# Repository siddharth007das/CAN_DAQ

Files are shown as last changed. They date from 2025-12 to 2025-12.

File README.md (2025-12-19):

# CAN-DAQ ESP32 PCB

This is the PCB for the ESP32 that is used in the CAN-DAQ project. Gerber files, BOM, and 3D printing files for the case are all available in the releases section on GitHub.

## Pin-out
Refer to the pin-out for [ESP32-S3 DevKitC 1](https://docs.espressif.com/projects/esp-idf/en/latest/esp32s3/hw-reference/esp32s3/user-guide-devkitc-1.html).

official pin-out

### Pin-out for the microcontroller

| ESP Pin | Function | Connected to |
| --- | --- | --- |
| GPIO6 | CAN Rx | MCP2651FD CAN Rx |
| GPIO7 | CAN Tx | MCP2651FD CAN Tx |
| GPIO4 | CAN Standby | MCP2651FD STBY (10k pull-down) |
| GPIO5 | Status | Status LED |
| GPIO46 | Disable debug log | Pull-up resistor (10k to 5V) |

### Pin-out for the DE9 CAN connector
| DE9 Pin | Function | Connected to |
| --- | --- | --- |
| 2 | CANL | MCP2651FD CANL |
| 7 | CANH | MCP2651FD CANH |
| 3 | CAN GND | GND |
| shield |  | GND |

## USB specification
| Property | Value |
| --- | --- |
| USB standard | USB 2.0 |
| Connector | USB micro-B |
| Maximum speed | 3 Mbit/s |

## Design decisions

### DE9 ground
The CAN ground of the DE9 connector is connected to the main ground of the circuit. In case the differential voltages are not referenced to the same ground, the CAN bus will not work properly otherwise.

Sources:
- https://electronics.stackexchange.com/a/519395/323565
- https://electronics.stackexchange.com/q/476129/323565

### ESP32 log output disable
The ESP32 has a pull-up resistor on GPIO46 to disable the debug log output. We do this to make ensure that our GUI software receives only clean data.

Source: [Section "8.3 ROM Messages Printing Control" of the ESP32-S3 Technical Reference Manual](https://www.espressif.com/sites/default/files/documentation/esp32-s3_technical_reference_manual_en.pdf)

### CAN Transceiver output enable
The MCP2651FD CAN transceiver has a STBY pin that can be used to enable or disable the transceiver. We use GPIO4 to control this pin. The STBY pin is pulled down to ground with a 10k resistor (enabled) by default.

Source: [Section "1.1 Mode Control Block" of the MCP2651FD datasheet](https://ww1.microchip.com/downloads/en/DeviceDoc/20005284A.pdf)

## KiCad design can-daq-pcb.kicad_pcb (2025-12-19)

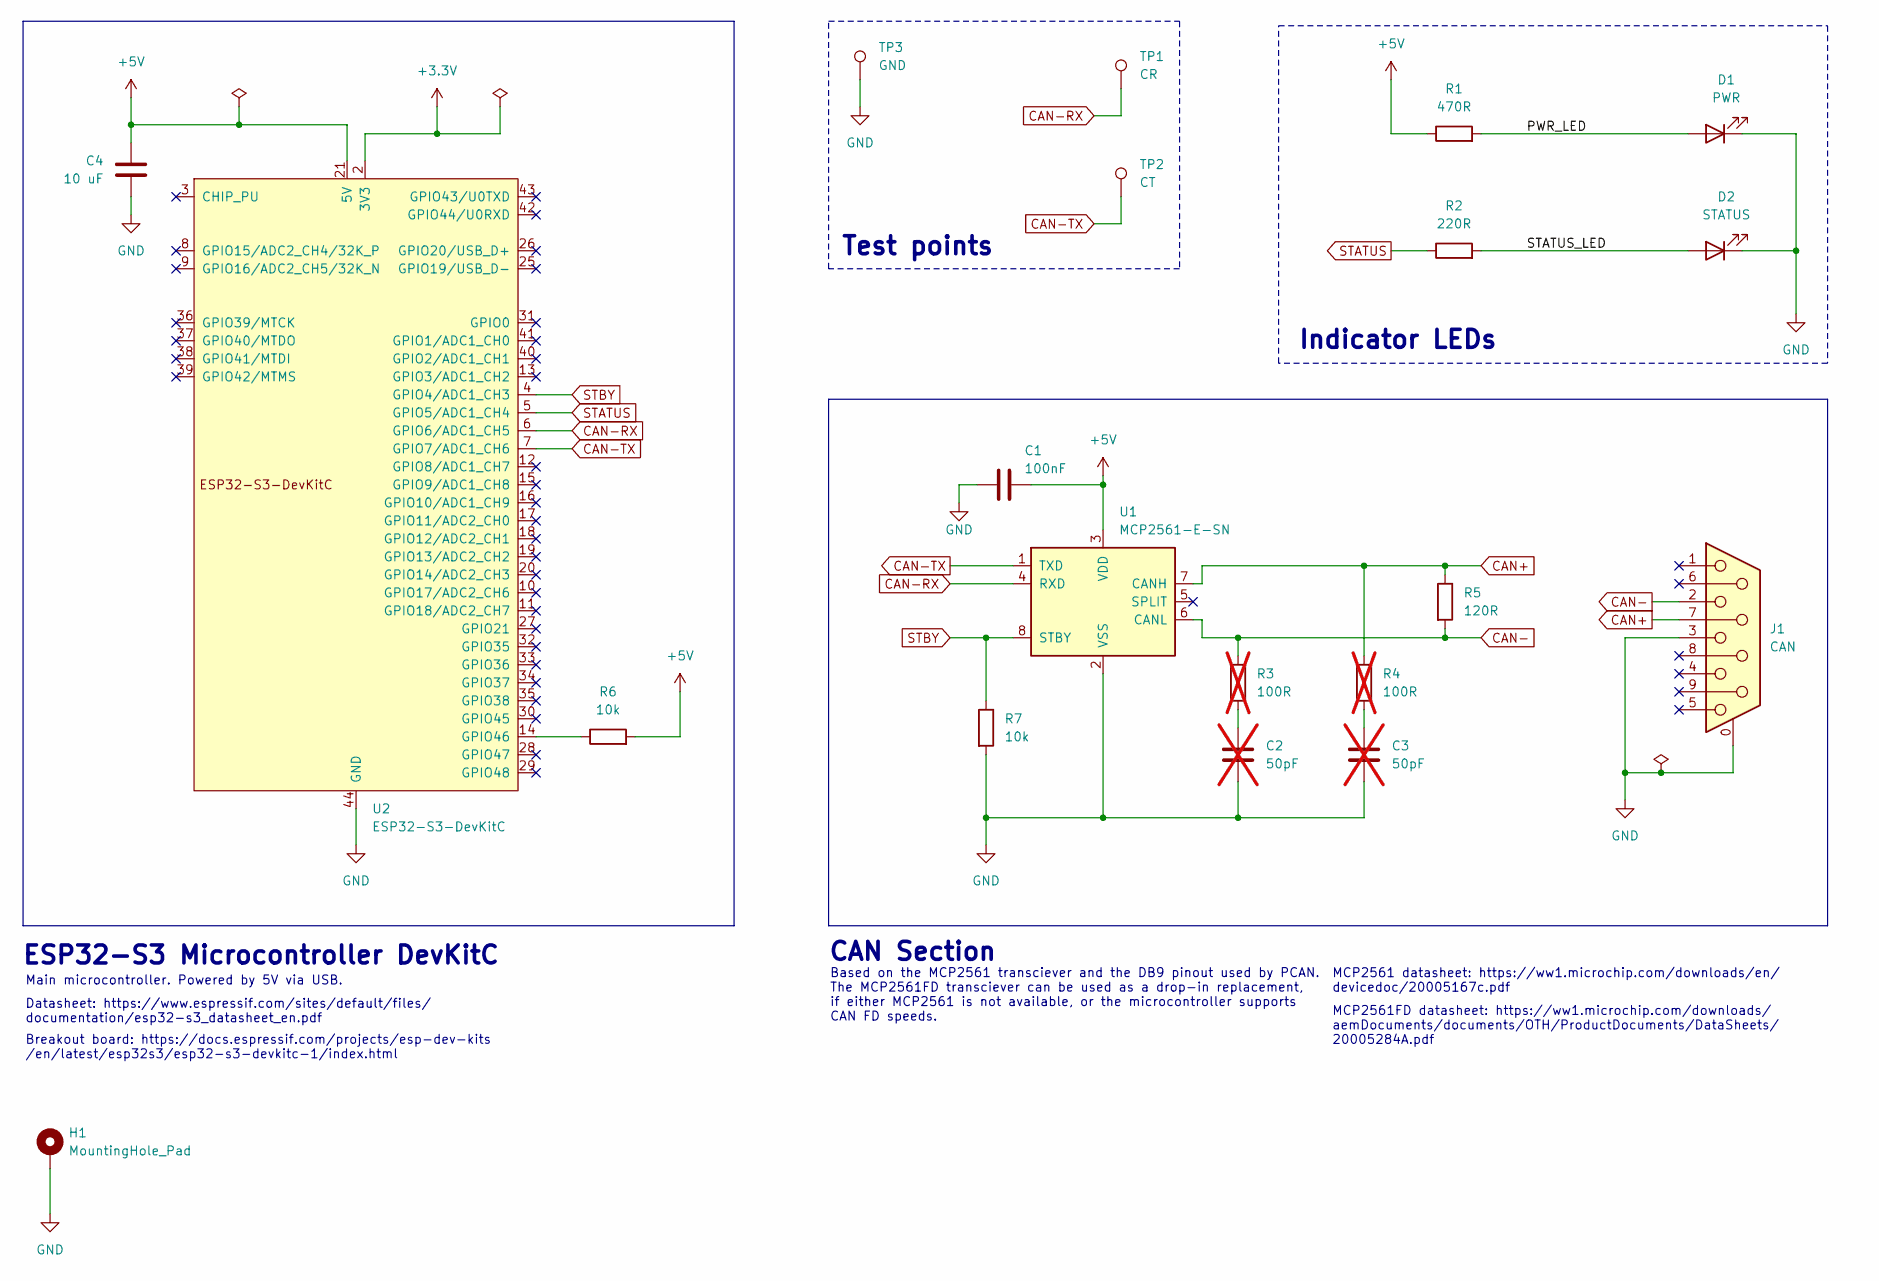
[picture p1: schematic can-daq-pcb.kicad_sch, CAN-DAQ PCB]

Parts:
C1: 100nF; C_0805_2012Metric_Pad1.18x1.45mm_HandSolder; MPN CC0805KRX7R9BB104; JLC C49678
C2, C3: 50pF; C_1206_3216Metric_Pad1.33x1.80mm_HandSolder; MPN FCC1206N470J102DT; JLC C5137553; not fitted
C4: 10 uF; C_1206_3216Metric_Pad1.33x1.80mm_HandSolder; MPN CL31A106KBHNNNE; JLC C13585
D1: PWR; LED_D3.0mm; MPN TZ-L2-03YYBR2RDJ30-003; JLC C779429
D2: STATUS; LED_D3.0mm; MPN TJ-L3FYTGCBMCGSFLC6B-A5; JLC C330760
H1: MountingHole_Pad; MountingHole_3.2mm_M3_Pad_Via
J1: CAN; DSUB-9_Female_Horizontal_P2.77x2.84mm_EdgePinOffset4.94mm_H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; MPN DS1037-09FNAKT74-0CC; JLC C75749
R1: 470R; R_1206_3216Metric_Pad1.30x1.75mm_HandSolder; MPN RC1206FR-07470RL; JLC C114945
R2: 220R; R_1206_3216Metric_Pad1.30x1.75mm_HandSolder; MPN 1206W4J0221T5E; JLC C25363
R3, R4: 100R; R_1206_3216Metric_Pad1.30x1.75mm_HandSolder; MPN 1206W4F1000T5E; JLC C17901; not fitted
R5: 120R; R_1206_3216Metric_Pad1.30x1.75mm_HandSolder; MPN 1206W4F1200T5E; JLC C17909
R6, R7: 10k; R_1206_3216Metric_Pad1.30x1.75mm_HandSolder; MPN 1206W4F1002T5E; JLC C17902
TP1: CR; TestPoint_THTPad_1.0x1.0mm_Drill0.5mm
TP2: CT; TestPoint_THTPad_1.0x1.0mm_Drill0.5mm
TP3: GND; TestPoint_THTPad_1.0x1.0mm_Drill0.5mm
U1: MCP2561-E-SN; SOIC-8_3.9x4.9mm_P1.27mm; MPN MCP2561-E/SN; JLC C219833
U2: ESP32-S3-DevKitC; MPN ESP32-S3-DEVKITC-1-N8; JLC C20438410

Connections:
+3.3V: U2.1 (3V3), U2.2 (3V3)
+5V: C1.1, C4.1, R1.1, R6.2, U1.3 (VDD), U2.21 (5V)
/PWR_LED: D1.2 (A), R1.2
/STATUS_LED: D2.2 (A), R2.2
CAN+: J1.7, R4.1, R5.1, U1.7 (CANH)
CAN-: J1.2, R3.1, R5.2, U1.6 (CANL)
CAN-RX: TP1.1, U1.4 (RXD), U2.6 (GPIO6/ADC1_CH5)
CAN-TX: TP2.1, U1.1 (TXD), U2.7 (GPIO7/ADC1_CH6)
GND: C1.2, C2.2, C3.2, C4.2, D1.1 (K), D2.1 (K), H1.1, J1.0 (PAD), J1.3, R7.2, TP3.1, U1.2 (VSS), U2.22 (GND), U2.23 (GND), U2.24 (GND), U2.44 (GND)
unnamed: C2.1, R3.2
unnamed: C3.1, R4.2
unnamed: R6.1, U2.14 (GPIO46)
STATUS: R2.1, U2.5 (GPIO5/ADC1_CH4)
STBY: R7.1, U1.8 (STBY), U2.4 (GPIO4/ADC1_CH3)

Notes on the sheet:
Main microcontroller. Powered by 5V via USB.
Based on the MCP2561 transciever and the DB9 pinout used by PCAN. The MCP2561FD transciever can be used as a drop-in replacement, if either MCP2561 is not available, or the microcontroller supports CAN FD speeds.
CAN Section
Indicator LEDs
Datasheet: https://www.espressif.com/sites/default/files/ documentation/esp32-s3_datasheet_en.pdf
Breakout board: https://docs.espressif.com/projects/esp-dev-kits /en/latest/esp32s3/esp32-s3-devkitc-1/index.html
MCP2561 datasheet: https://ww1.microchip.com/downloads/en/ devicedoc/20005167c.pdf
MCP2561FD datasheet: https://ww1.microchip.com/downloads/ aemDocuments/documents/OTH/ProductDocuments/DataSheets/ 20005284A.pdf
ESP32-S3 Microcontroller DevKitC
Test points

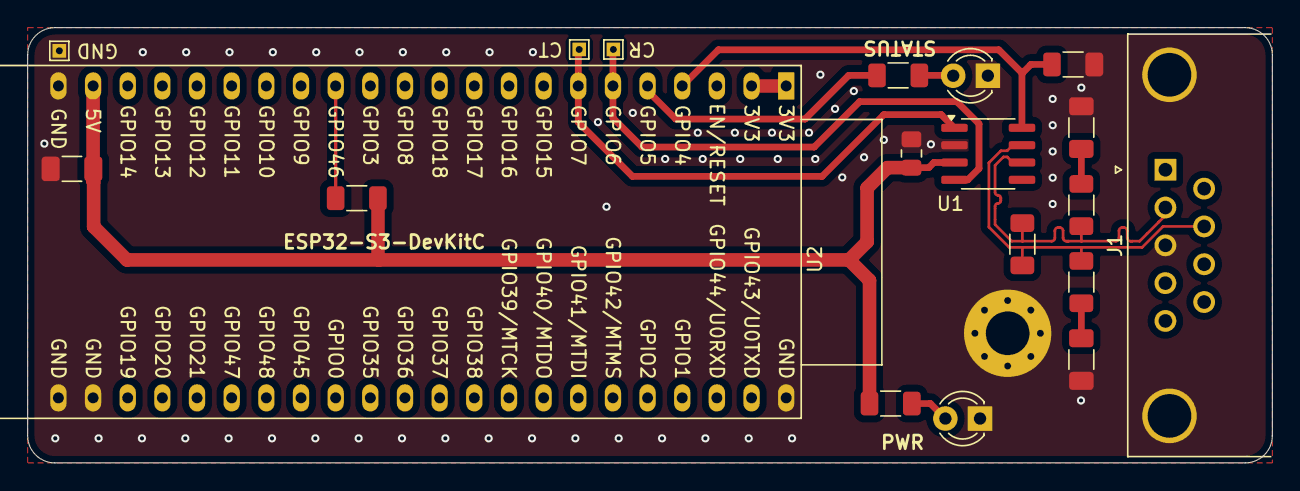
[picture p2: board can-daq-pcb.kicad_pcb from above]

Board: 2 copper layers, 91.2 x 31.9 mm, 20 parts (0 on the bottom side), 14 nets.
